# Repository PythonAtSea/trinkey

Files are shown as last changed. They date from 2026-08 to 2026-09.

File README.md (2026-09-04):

# Trinkey

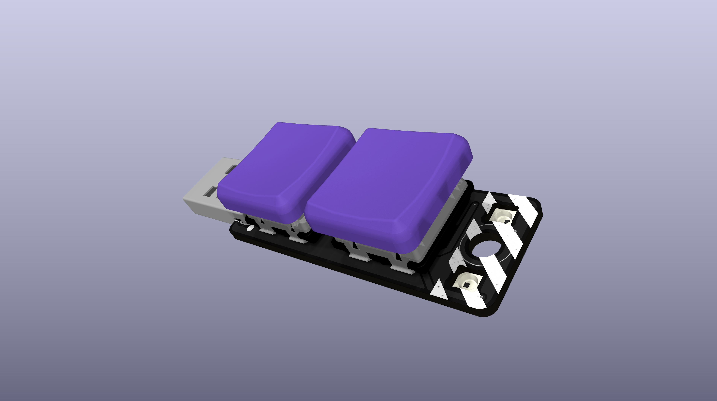
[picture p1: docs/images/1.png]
hero image

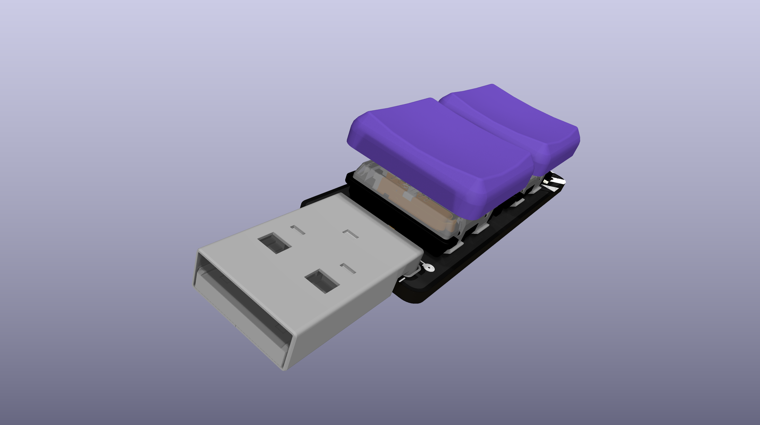
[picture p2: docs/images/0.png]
hero image

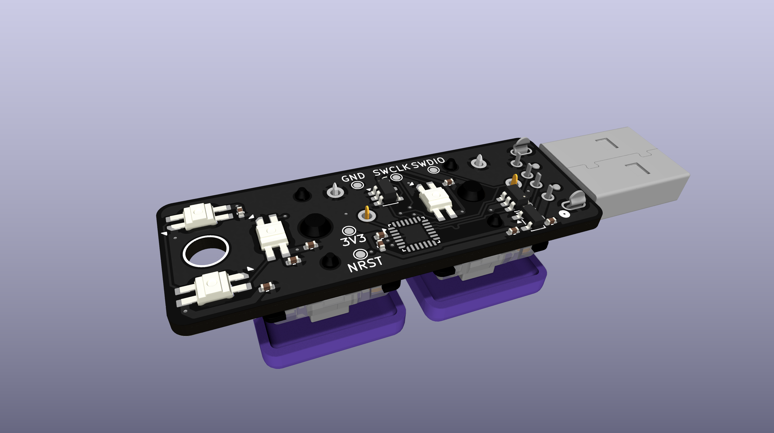
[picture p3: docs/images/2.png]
hero image


Trinkey is a STM32 based keychain trinket. It has two Kailh switches, each with  a MBK low profile keycap and a reverse mounted SK6812MINI-E RGB LED. Additionally, there are two more reverse mounted SK6812MINI-E next to the keyring. It also has a male USB-A plug which powers the device and provides USB FS connectivity. 

## Screenshots

##### SVG export of schematic
schematic
##### Combined export of PCB
pcb combined view
##### Top export of PCB
pcb top view
##### Bottom export of PCB
pcb bottom view

## Flashing Software

The Trinkey has pads for flashing using **S**erial **W**ire **D**ebug. If you're getting one of these thru [Hack Club Gadget Market](https://gadget.hackclub.com), it will be pre flashing with a bootloader that supports uploading code over USB using the Ardunio IDE. It will also have some sort of example program, but that is still TBD. I will also design a jig for holding contact against the test pads for flashing over SWD.

## Bill of Materials

| Item | Vendor | Price |
|---|---|---|
|PCB|JLCPCB|$70.43|
|[USB-A plug](https://www.digikey.com/en/products/detail/molex/0480370001/857603)|Digikey|$10.38|
|Shipping|Digikey|$4.99|
|Tariff|Digikey|$2.08|
|Sales tax|Digikey|$1.22|
|[SK6812MINI-E (25 pack)](https://keeb.io/products/sk-6812-mini-e-rgb-leds-12-pack)|Keebs.io|$5.99|
|[Kailh low profile switches](https://keeb.io/products/kailh-choc-low-profile-switches-v1)|Keebs.io|$7.20|
|[MBK PBT Blank keycaps](https://keeb.io/products/mbk-keycaps)|Keebs.io|$4.41|
|Shipping|Keebs.io|$7.90|
|[ST-LINK/V2 (mini)](https://www.waveshare.com/st-link-v2-mini-stm32.htm)|Waveshare|$8.99|
|Shipping|Waveshare|$10.00|
|**Total**| |**$133.59**|

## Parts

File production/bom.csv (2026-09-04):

Designator | Footprint | Quantity | Value | LCSC Part #
C1, C2 | 0402 | 2 | 1u
C3, C6, C7, C8, C9 | 0402 | 5 | 100n
C4 | 0402 | 1 | 4.7u
C5 | 0402 | 1 | 10u
CH1, CH2 | SW_choc_v1_1u | 2 | choc_v1_SW_solder
J1 | CONN_480370001_MOL | 1 | USB_A
LED1, LED2 | LED_choc_6028R | 2 | choc_SK6812MINI-E
LED3, LED4 | LED_6028R | 2 | SK6812MINI-E
R1 | 0402 | 1 | 47
TP1 | TestPoint_Pad_D1.0mm | 1 | SWDIO
TP2 | TestPoint_Pad_D1.0mm | 1 | SWCLK
TP3 | TestPoint_Pad_D1.0mm | 1 | NRST
TP4 | TestPoint_Pad_D1.0mm | 1 | 3V3
TP5 | TestPoint_Pad_D1.0mm | 1 | GND
U1 | QFN-28_4x4mm_P0.5mm | 1 | STM32C071G8Ux | C44521811
U2 | SOT-23-3 | 1 | XC6206PxxxMR | C347376
U3 | SOT-23-6 | 1 | USBLC6-2SC6 | C2687116
U4 | SOT-23-5 | 1 | 74AHCT1G125 | C7484

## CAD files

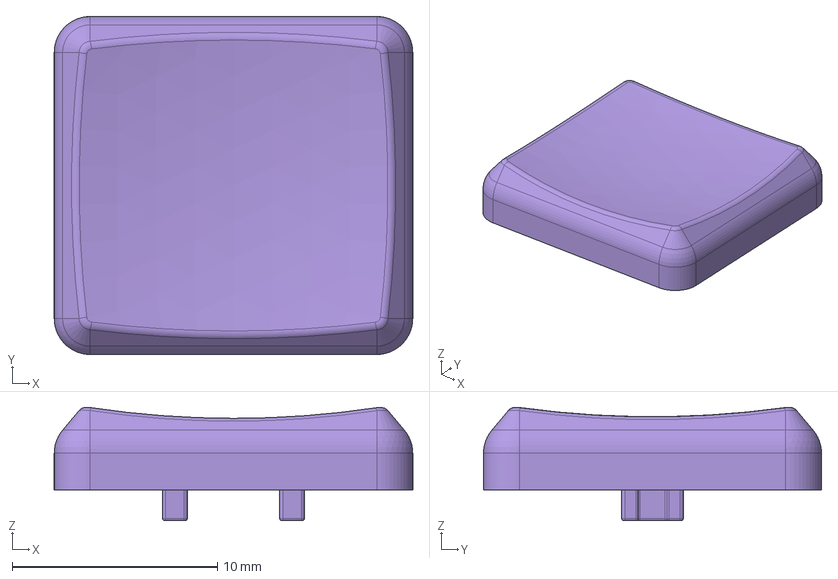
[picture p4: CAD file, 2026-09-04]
3dModels/MBK_Keycap_-_1u.step
17.4 x 16.4 x 5.52 mm

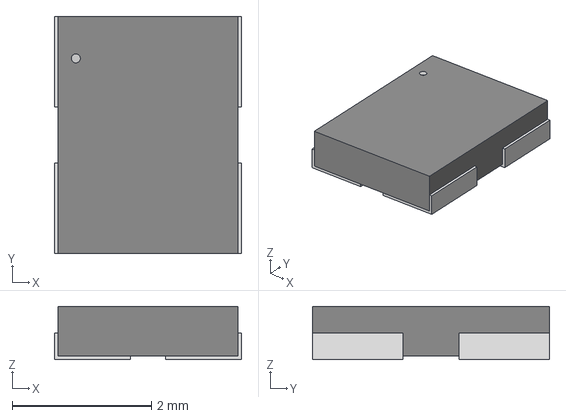
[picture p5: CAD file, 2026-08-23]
ul_ABM8-272-T3/ABM8-272-T3_ABR.step
2.69 x 3.40 x 0.765 mm

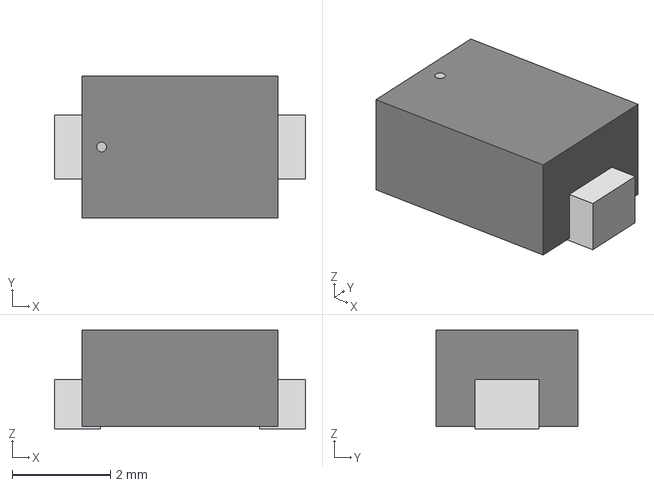
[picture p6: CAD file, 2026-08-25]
ul_TS-1088-AR02016/SW_TS-1088_XNP.step
5.11 x 2.90 x 2.01 mm

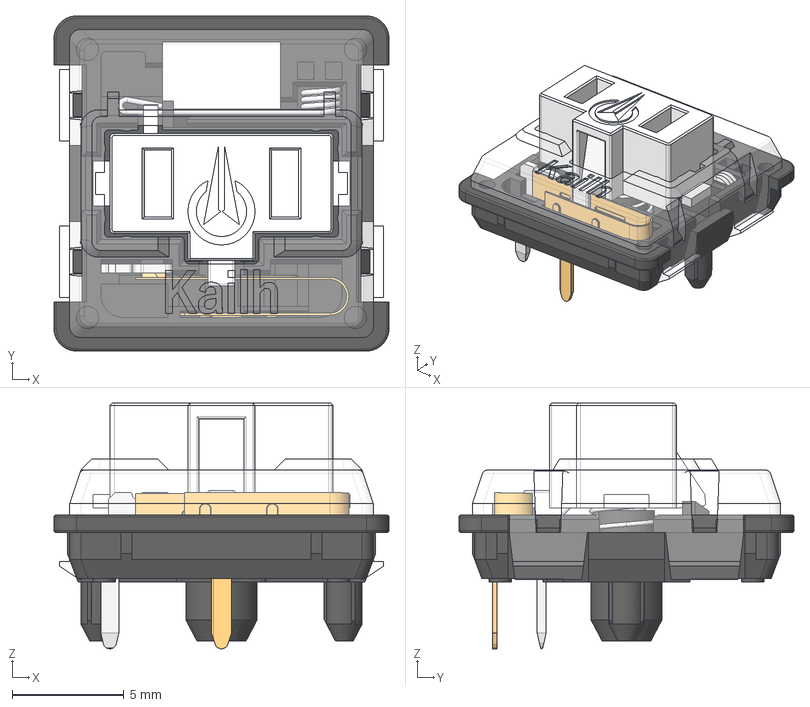
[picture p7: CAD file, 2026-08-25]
3dModels/white.step
15.0 x 15.0 x 11.0 mm
stem
pin1
top
shrunken_spring
pin2
contact
bottom
click_bar

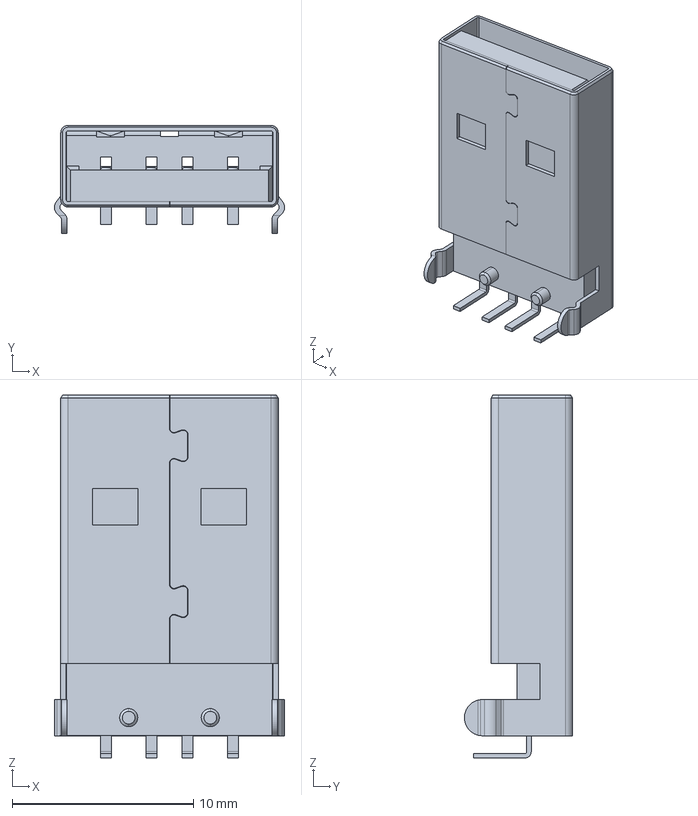
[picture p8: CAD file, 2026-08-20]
ul_480370001/480370001.stp
12.7 x 5.97 x 20.0 mm

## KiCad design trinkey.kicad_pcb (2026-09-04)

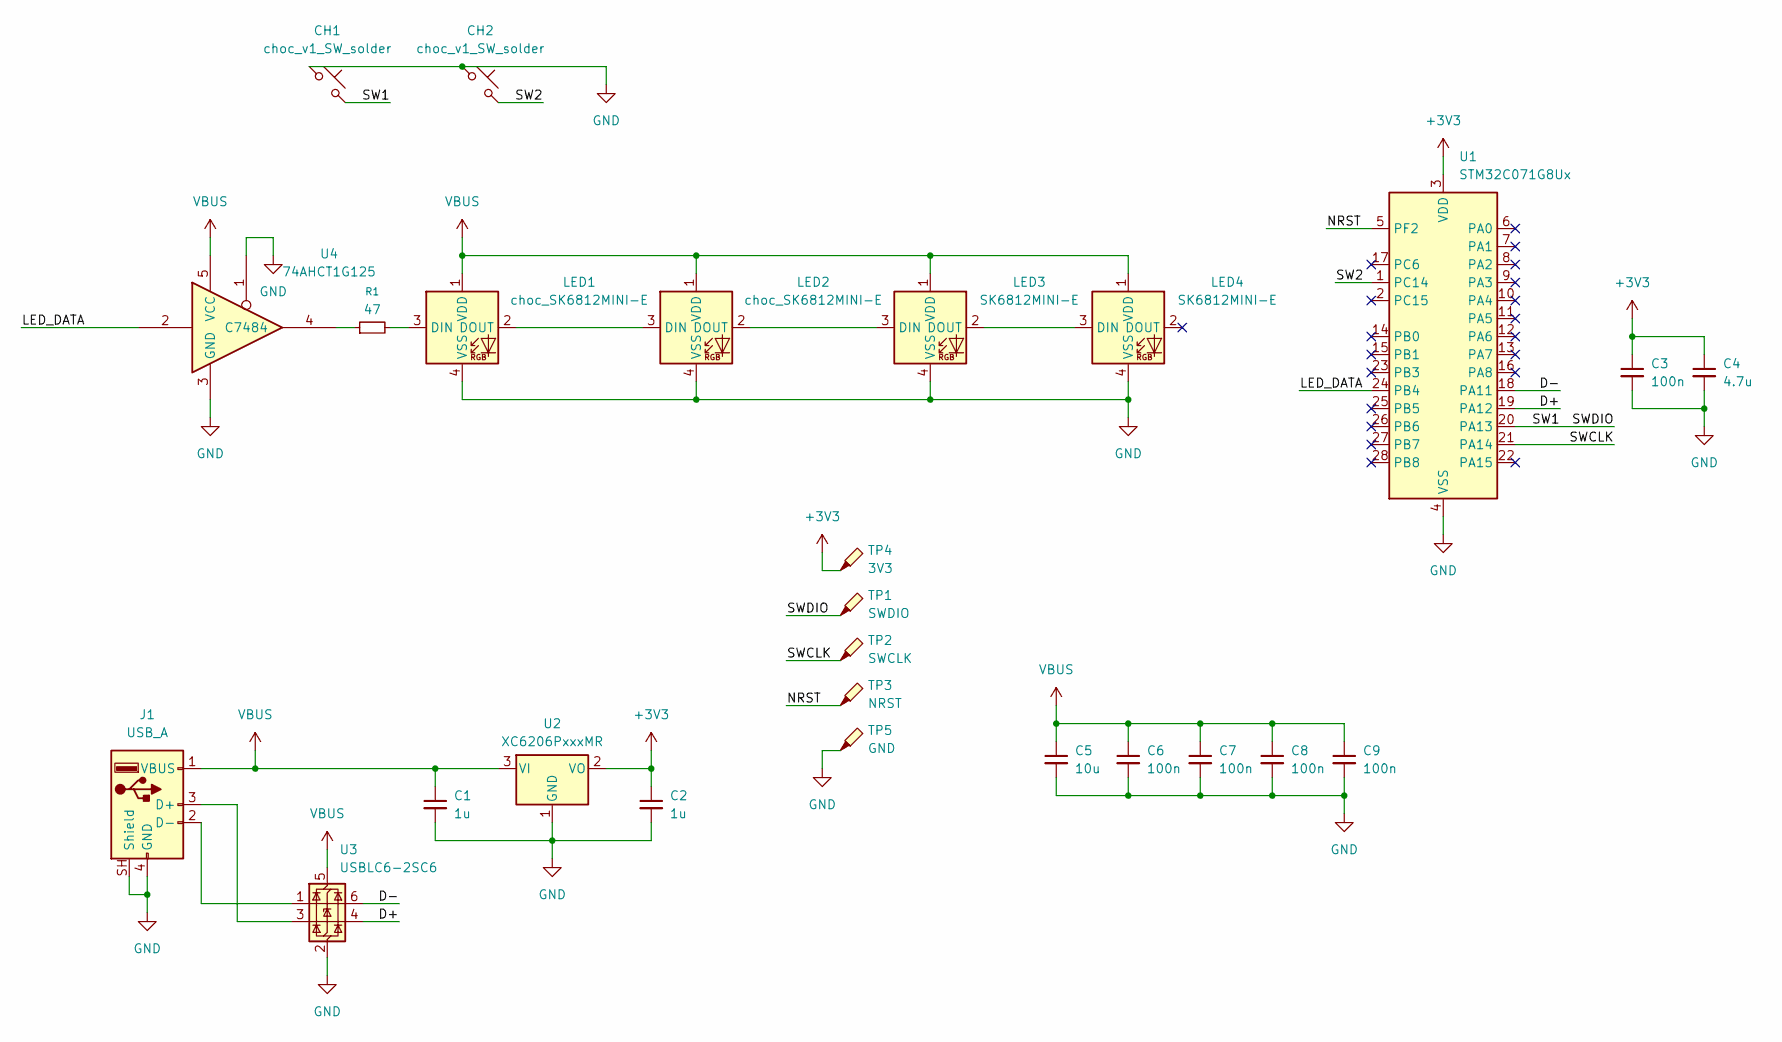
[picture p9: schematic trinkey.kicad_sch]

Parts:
C1, C2: 1u; C_0402_1005Metric; LCSC Part # C52923
C3, C6, C7, C8, C9: 100n; C_0402_1005Metric; LCSC Part # C1525
C4: 4.7u; C_0402_1005Metric; LCSC Part # C23733
C5: 10u; C_0402_1005Metric; LCSC Part # C15525
CH1, CH2: choc_v1_SW_solder; SW_choc_v1_1u
J1: USB_A; CONN_480370001_MOL
LED1, LED2: choc_SK6812MINI-E; LED_choc_6028R
LED3, LED4: SK6812MINI-E; LED_6028R
R1: 47; R_0402_1005Metric; LCSC Part # C25792
TP1: SWDIO; TestPoint_Pad_D1.0mm
TP2: SWCLK; TestPoint_Pad_D1.0mm
TP3: NRST; TestPoint_Pad_D1.0mm
TP4: 3V3; TestPoint_Pad_D1.0mm
TP5: GND; TestPoint_Pad_D1.0mm
U1: STM32C071G8Ux; QFN-28_4x4mm_P0.5mm; LCSC Part # C44521811
U2: XC6206PxxxMR; SOT-23-3; LCSC Part # C347376
U3: USBLC6-2SC6; SOT-23-6; LCSC Part # C2687116
U4: 74AHCT1G125; SOT-23-5; LCSC Part # C7484

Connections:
+3V3: C2.1, C3.1, C4.1, TP4.1 (1_1), U1.3 (VDD), U2.2 (VO)
/D+: U1.19 (PA12), U3.4 (I/O2)
/D-: U1.18 (PA11), U3.6 (I/O1)
/LED_DATA: U1.24 (PB4), U4.2
/NRST: TP3.1 (1_1), U1.5 (PF2)
/SW1: CH1.2, TP1.1 (1_1), U1.20 (PA13)
/SW2: CH2.2, U1.1 (PC14)
/SWCLK: TP2.1 (1_1), U1.21 (PA14)
GND: C1.2, C2.2, C3.2, C4.2, C5.2, C6.2, C7.2, C8.2, C9.2, CH1.1, CH2.1, J1.4 (GND), J1.SH (Shield), LED1.4 (VSS), LED2.4 (VSS), LED3.4 (VSS), LED4.4 (VSS), TP5.1 (1_1), U1.4 (VSS), U2.1 (GND), U3.2 (GND), U4.1, U4.3 (GND)
unnamed: J1.3 (D+), U3.3 (I/O2)
unnamed: J1.2 (D-), U3.1 (I/O1)
unnamed: LED1.3 (DIN), R1.2
unnamed: LED1.2 (DOUT), LED2.3 (DIN)
unnamed: LED2.2 (DOUT), LED3.3 (DIN)
unnamed: LED3.2 (DOUT), LED4.3 (DIN)
unnamed: R1.1, U4.4
VBUS: C1.1, C5.1, C6.1, C7.1, C8.1, C9.1, J1.1 (VBUS), LED1.1 (VDD), LED2.1 (VDD), LED3.1 (VDD), LED4.1 (VDD), U2.3 (VI), U3.5 (VBUS), U4.5 (VCC)

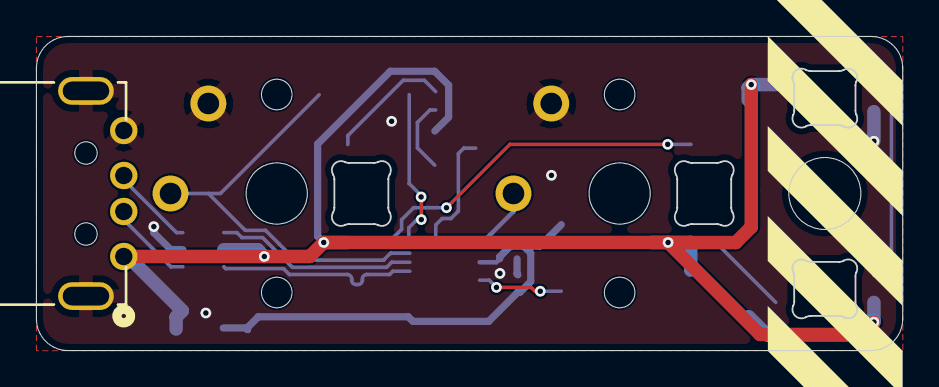
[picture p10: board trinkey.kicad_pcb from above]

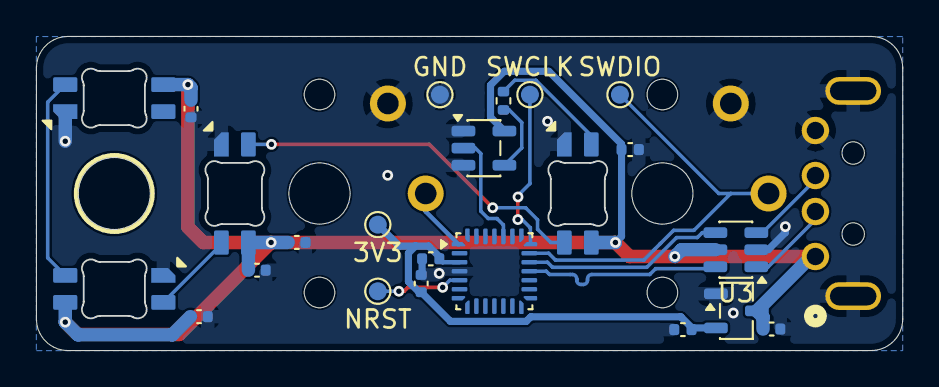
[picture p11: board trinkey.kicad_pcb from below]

Board: 2 copper layers, 48.1 x 17.5 mm, 26 parts (23 on the bottom side), 17 nets.

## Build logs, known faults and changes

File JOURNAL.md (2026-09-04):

---
title: "trinkey"
github: "pythonatsea/trinkey"
description: "small rp2040 based keychain devboard"
created_at: "08-19-2026"
---

## August 19th: let's get started! (1 hour)

The plan for this is to have a rp2040 with two keyswitches and a male USB-A plug. I also want to have some RGB LEDs, maybe reverse mounted under the keyswitches.

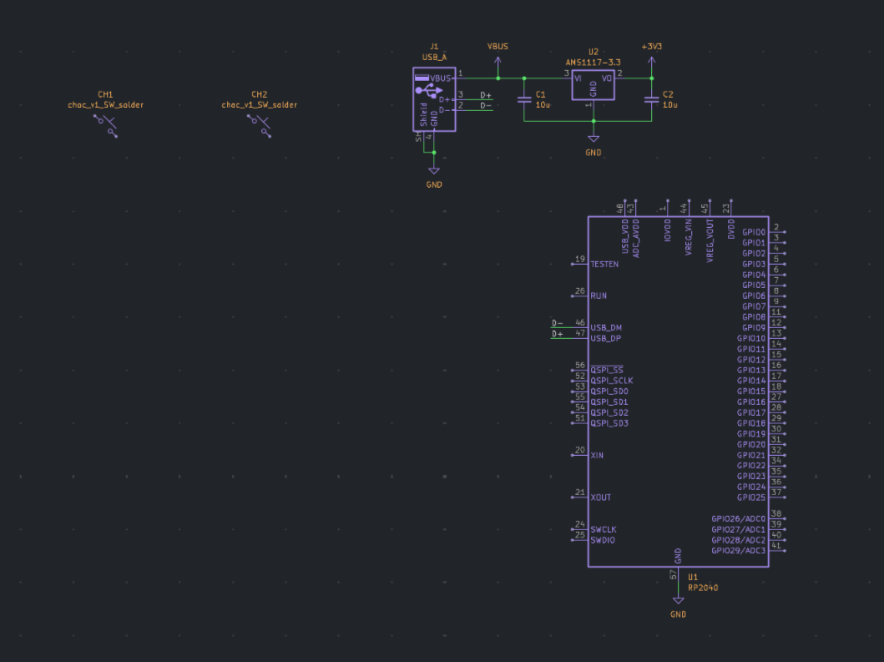
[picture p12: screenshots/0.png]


## August 22nd: supporting rp2040 electronics. (45 minutes)

I got all of the necessary circuitry for the rp2040 added. I'm following the design guide exactly, except for the voltage regulator. I'm using a different one because it's on JLCPCB's basic parts list so I don't have to pay a reeling fee.

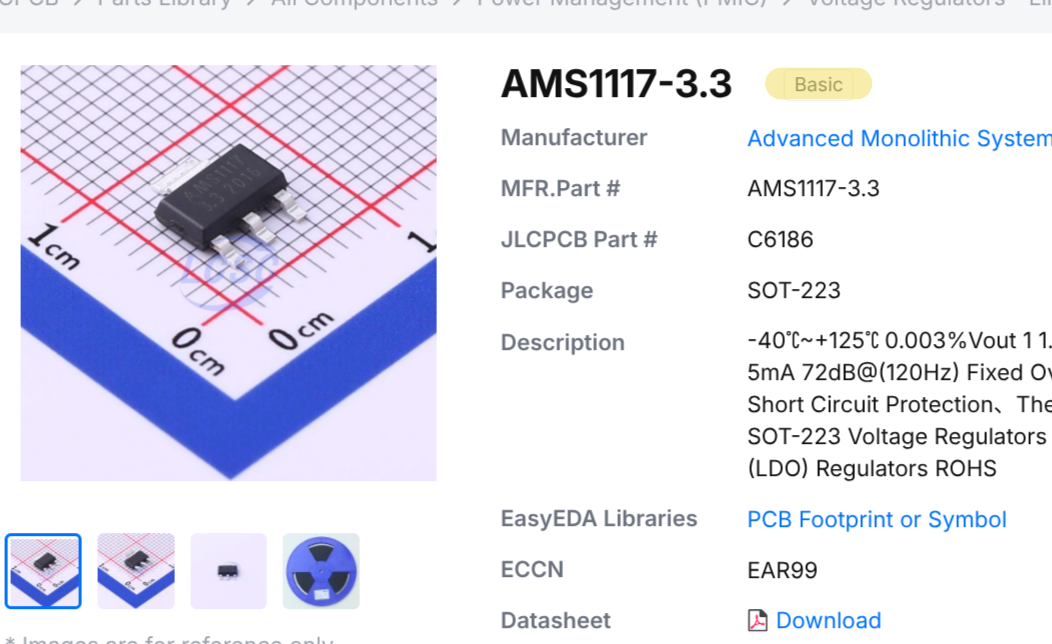
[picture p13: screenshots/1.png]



## August 24th: Packaging is *hard* (2 hours 15 minutes)

I started working on the PCB layout. I want to have two Kailh Choc switches, both with reverse mounted SK6812MINI-E addressable LEDs. First, I got the switches and LEDs put into position. However, once I started trying to cram the rp2040 and the flash chip things got annoying. I spent a lot of time trying different ways of fitting them, but I couldn't get them to work with the PCB size that I had chosen. I don't really want to make the PCB much bigger, so I might have to switch MCUs to something that's physically smaller. On a positive note, I was able to get 3d models for *both* the switches and the keycaps!

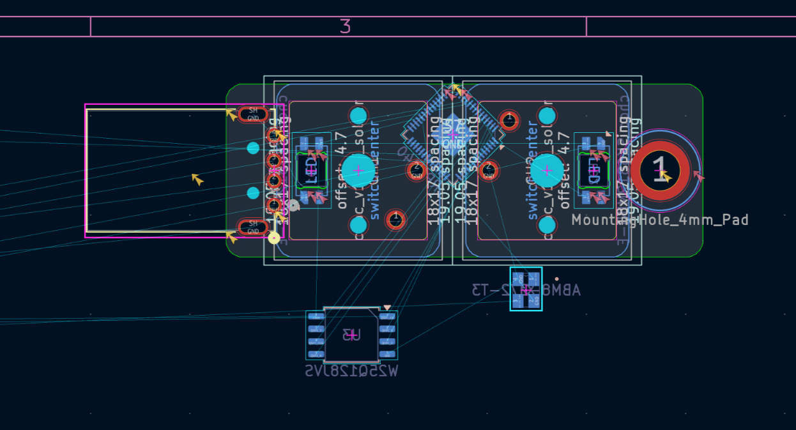
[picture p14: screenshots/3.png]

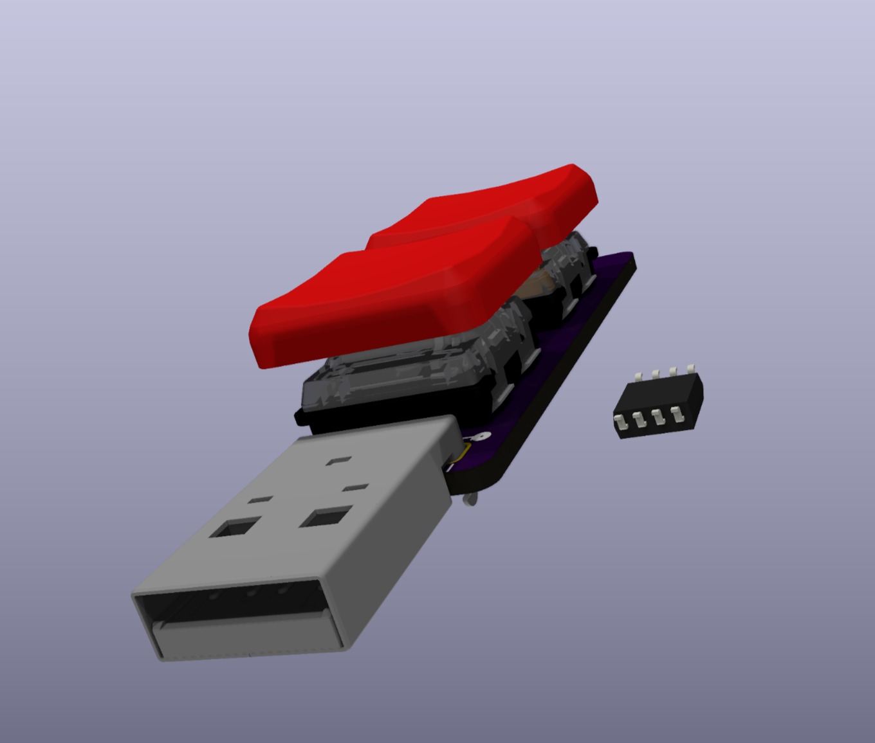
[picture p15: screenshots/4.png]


## August 30th: Switching to the STM32 (3 hours)

I spent a bit more time trying to get everything to fit with the rp2040, but it just wasn't gonna work. I decided to switch to the STM32, which supports USB HID and is physically very small. One thing I liked about it's datasheet is this diagram showing the exact part number combos:
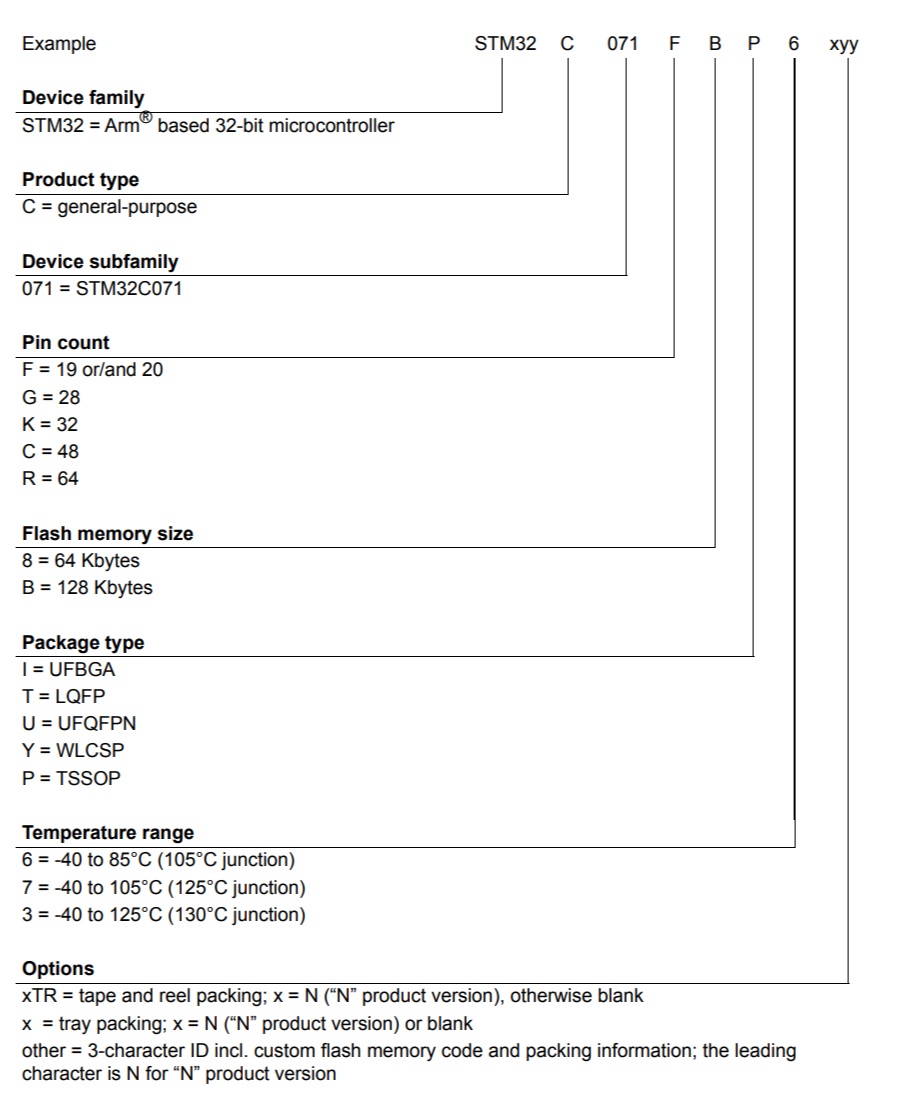
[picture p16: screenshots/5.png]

I also changed the 3v3 regulator to smaller one, cuz the one the rp2040 design guide recommends was much too big. The STM32 is quite easy to wire up, which I liked. I also got to power and some of the other routing done:
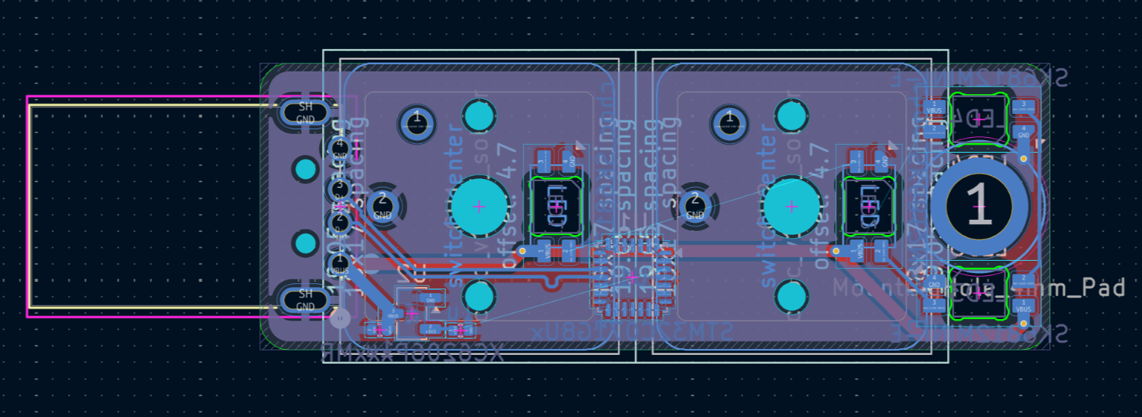
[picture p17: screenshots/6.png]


## September 3rd: 80/20, 20/80 (2 hours 30 minutes)

The first 80% takes 20% of the effort, and the last 20% takes 80%. Maybe not that extreme, but pretty close. I ran the DRC and discovered that there were quite a few issues, including overlapping components. Additionally, I remembered to add a level shifter for the LED data line. I also had to source parts for everything. Around half of the parts are being assembled by JLCPCB. The rest include the Sk6812MINI-Es, the USB-A plug, the Kailh switches, and the keycaps (obviously JLC isn't soldering on the keycaps). I'm getting the LEDs, the keycaps, and the switches from [Keebs.io](https://keebs.io). I'm getting the USB-A plug from Digikey, and I'm also getting a SWD programmer from Waveshare.

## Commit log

2026-08-20 feat: basic stuff
    [480370001.stp, trinkey.kicad_pcb, trinkey.kicad_sch]
2026-08-23 feat: basic rp2040 circuitry
    [ABM8-272-T3_ABR.step, trinkey.kicad_sch]
2026-08-25 feat: packaging ahhhhh
    [MBK_Keycap_-_1u.step, SW_TS-1088_XNP.step, trinkey.kicad_pcb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]
2026-08-31 feat: switch to the STM32
    [trinkey.kicad_pcb, trinkey.kicad_sch]
2026-09-04 feat: polishing and readme
    [MBK_Keycap_-_1u.step, bom.csv, designators.csv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]
2026-09-04 feat: add exports of PCB and schematic to README
    [trinkey.kicad_sch]
